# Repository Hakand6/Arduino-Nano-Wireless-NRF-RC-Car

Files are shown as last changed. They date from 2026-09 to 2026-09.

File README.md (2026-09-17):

# Arduino-Nano-Wireless-NRF-RC-Car
# DIY Wireless RC Car & Custom Transmitter

Bu proje, tamamen sıfırdan tasarlanmış ve üretilmiş, kablosuz (RF) iletişimle kontrol edilen özel bir uzaktan kumandalı araba ve kumanda sistemidir. Hem donanımsal hem de yazılımsal olarak tüm süreçler (3D tasarım, devre tasarımı ve Arduino kodlaması) bu repoda yer almaktadır.

 Kullanılan Bileşenler

### Araç (Alıcı Tarafı):
* **Mikrokontrolcü:** Arduino Nano
* **Kablosuz Haberleşme:** NRF24L01 Transceiver Modülü
* **Motor Kontrolü:** Çift kanallı röle modülü & Güçlü DC Motor
* **Güç Yönetimi:** 12V Batarya ve ekranlı/voltaj göstergeli voltaj regülatörü
* **Aydınlatma:** Alt taban RGB LED aydınlatma
* **Şasi:** Özel 3D tasarım ve baskı parça bileşenleri

### Kumanda (Verici Tarafı):
* **Mikrokontrolcü:** Arduino Nano
* **Kablosuz Haberleşme:** NRF24L01 Transceiver Modülü
* **Giriş Elemanları:** Joystick ve potansiyometreler (Adaptif hız kontrolü için)

##  Özellikler
* **Özel Tasarım Kumanda:** Ergonomik, kendi üretimimiz olan 3D baskı kumanda kasası.
* **Adaptif Hız Kontrolü:** Kumanda üzerindeki girdilere duyarlı olarak anlık hız artırıp azaltabilme.
* **Canlı Voltaj Takibi:** Ekranlı regülatör sayesinde anlık batarya voltajı izleme (düşük voltaj/şarj bitti uyarısı).
* **Kablosuz Kontrol:** NRF24L01 modülleri ile kesintisiz ve kararlı sinyalleşme.
* **Görsel Detaylar:** Aracın alt kısmına entegre edilmiş RGB LED'ler.

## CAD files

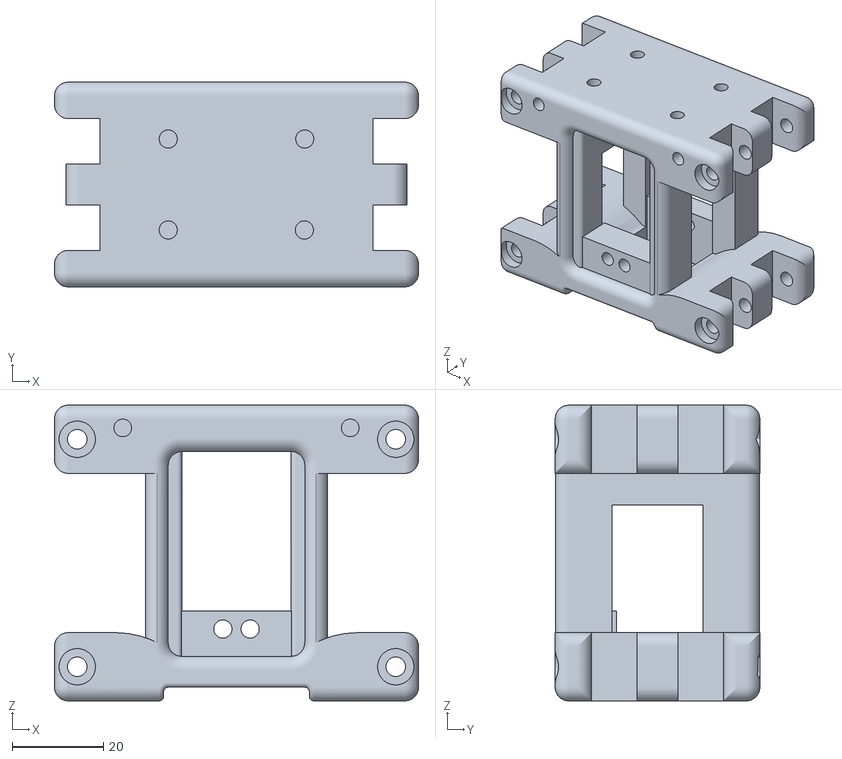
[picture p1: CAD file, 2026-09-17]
3d Printed Files/Main Suspension Hub Connector Front.STL
80.0 x 45.0 x 65.0

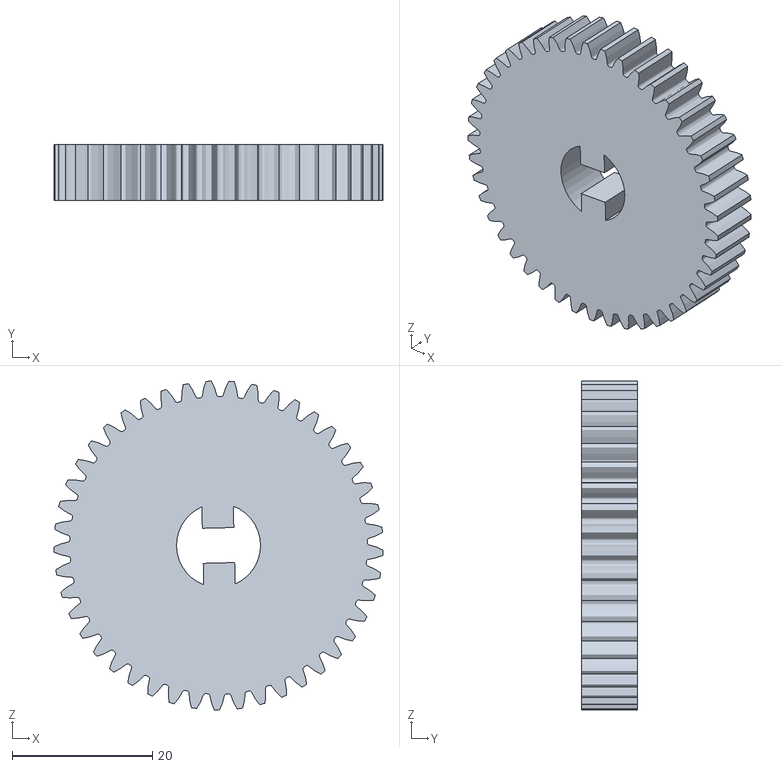
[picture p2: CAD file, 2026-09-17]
3d Printed Files/Gearbox Assembly - 45 Teeth Gear-1.STL
47.0 x 8.00 x 47.0

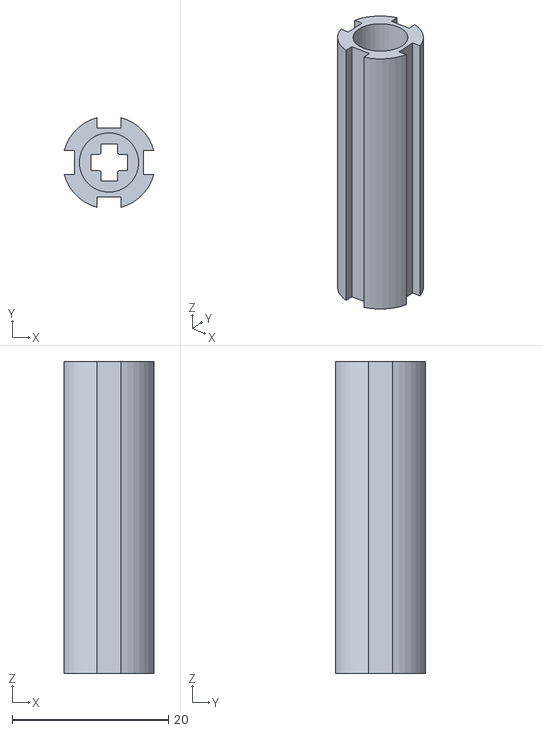
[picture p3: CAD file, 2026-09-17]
3d Printed Files/Main Rear Axle.STL
11.5 x 11.5 x 40.0

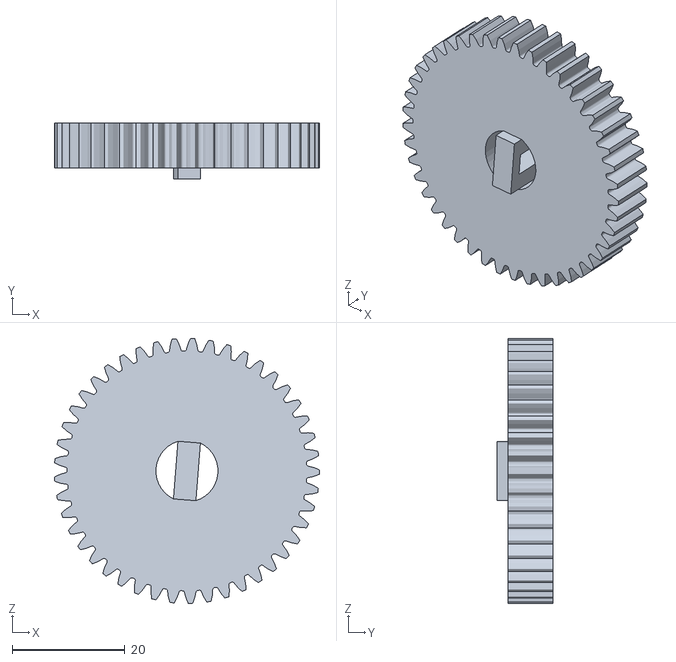
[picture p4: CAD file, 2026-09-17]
3d Printed Files/Gearbox Assembly - 45 15 Gear (2).STL
47.0 x 10.0 x 47.0

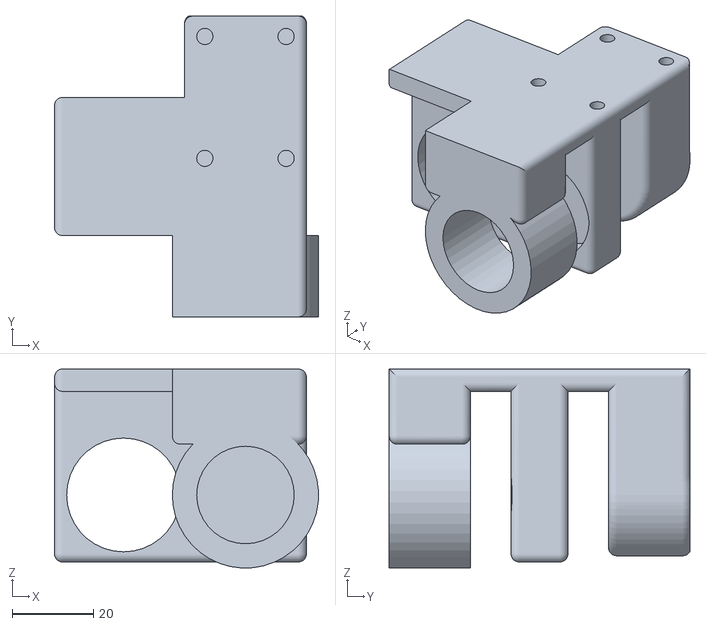
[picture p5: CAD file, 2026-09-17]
3d Printed Files/Gearbox Assembly - Motor Mount-1.STL
65.0 x 74.0 x 49.0

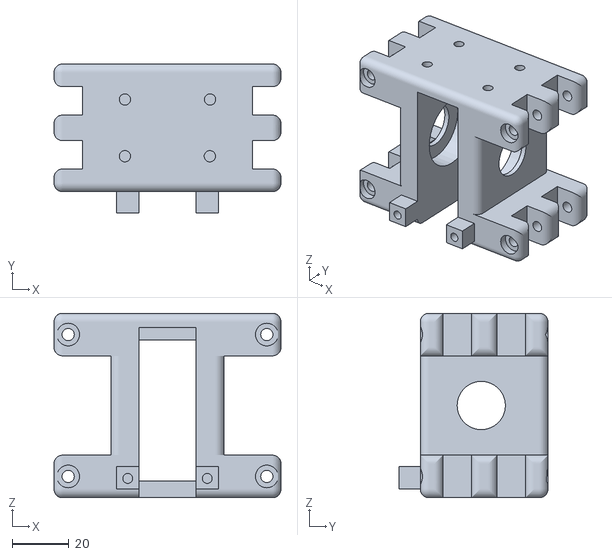
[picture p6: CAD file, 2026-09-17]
3d Printed Files/Main Suspension Hub Connector Rear.STL
80.0 x 52.5 x 65.0

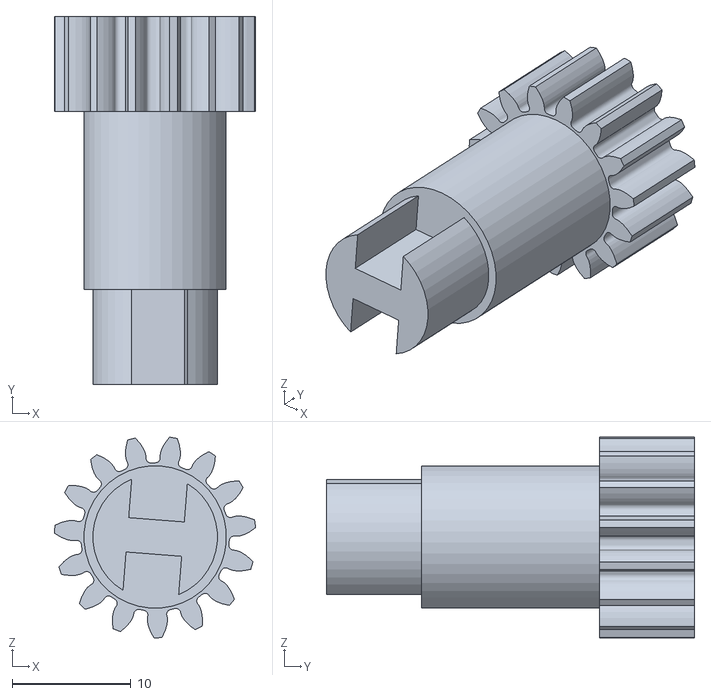
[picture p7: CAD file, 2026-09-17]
3d Printed Files/Gearbox Assembly - 45 15 Gear (1).STL
17.0 x 31.0 x 16.9

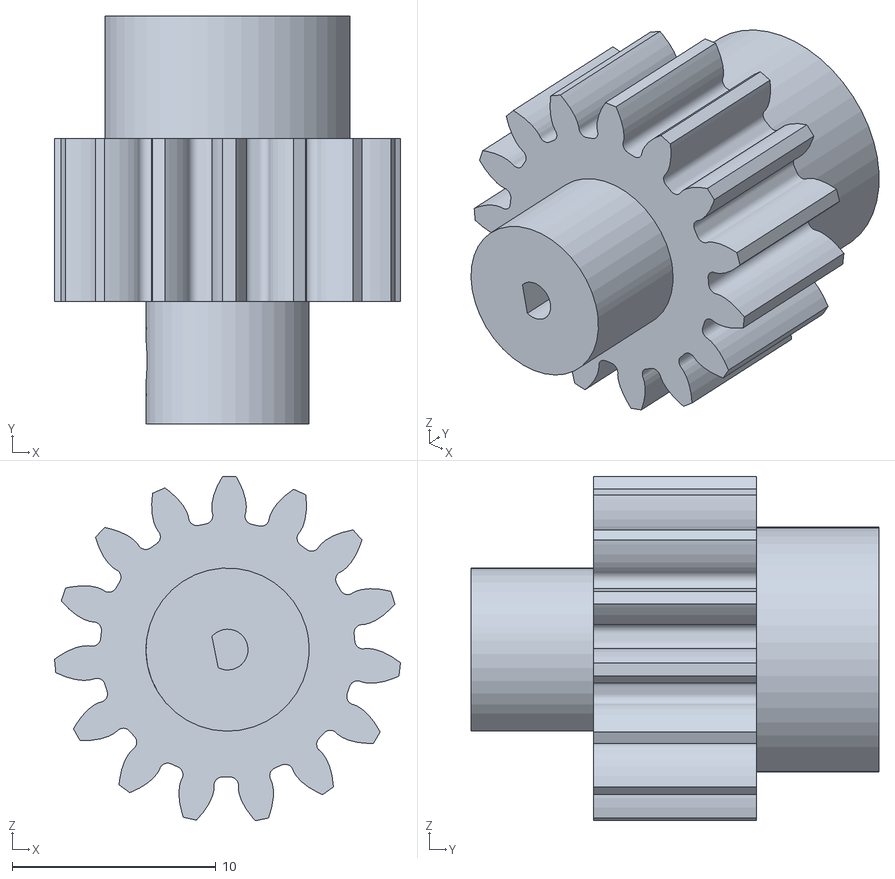
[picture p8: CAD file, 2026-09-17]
3d Printed Files/Gearbox Assembly - Motor Gear-1.STL
17.0 x 20.0 x 16.9

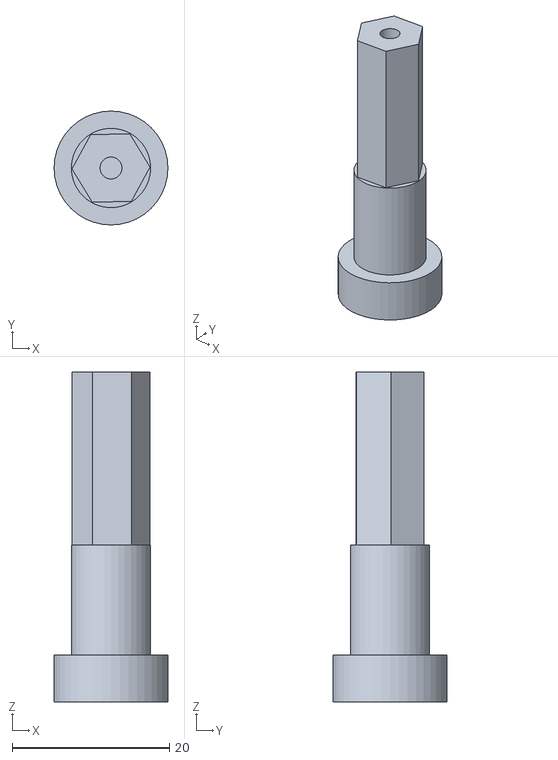
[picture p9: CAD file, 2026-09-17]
3d Printed Files/Front Wheel Connector.STL
14.5 x 14.5 x 42.0

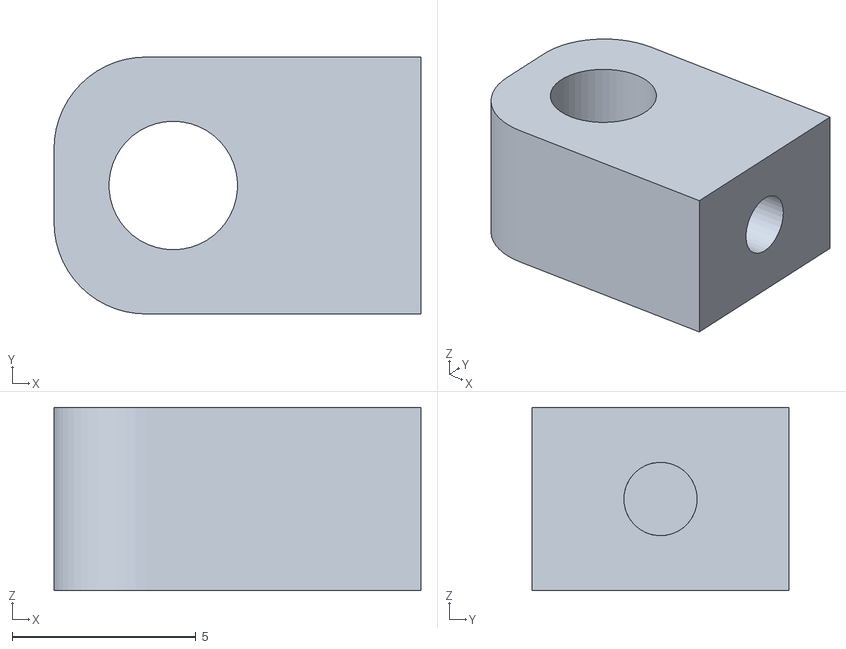
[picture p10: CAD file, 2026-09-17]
amortısor/obj_4_实体9.stl
10.0 x 7.00 x 5.00

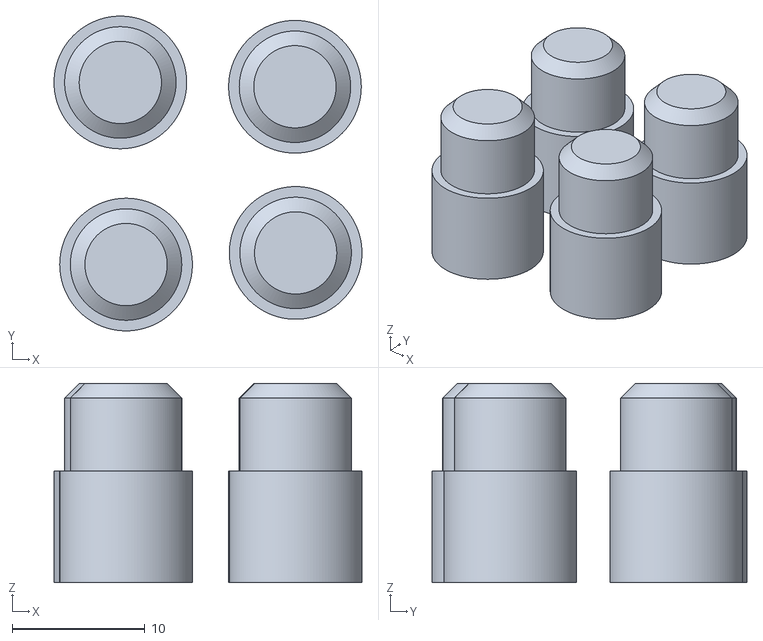
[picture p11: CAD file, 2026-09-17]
rc kumanda/obj_1_Buttons.stl
23.2 x 23.7 x 15.0

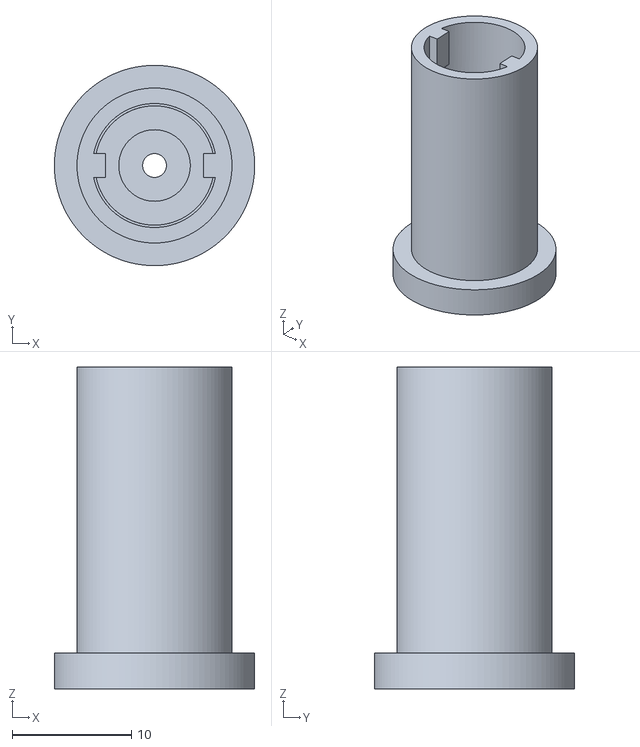
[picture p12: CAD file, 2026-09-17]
amortısor/obj_2_实体2.stl
16.8 x 16.8 x 27.0

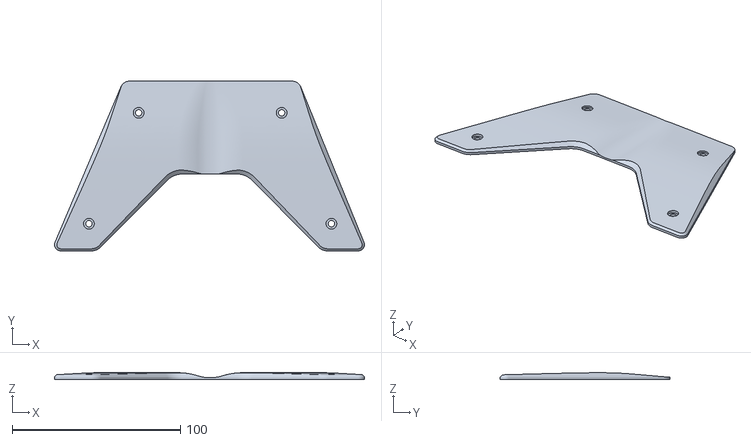
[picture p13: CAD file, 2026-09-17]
rc kumanda/obj_2_COMPOUND_6.stl
184.0 x 100.8 x 3.92

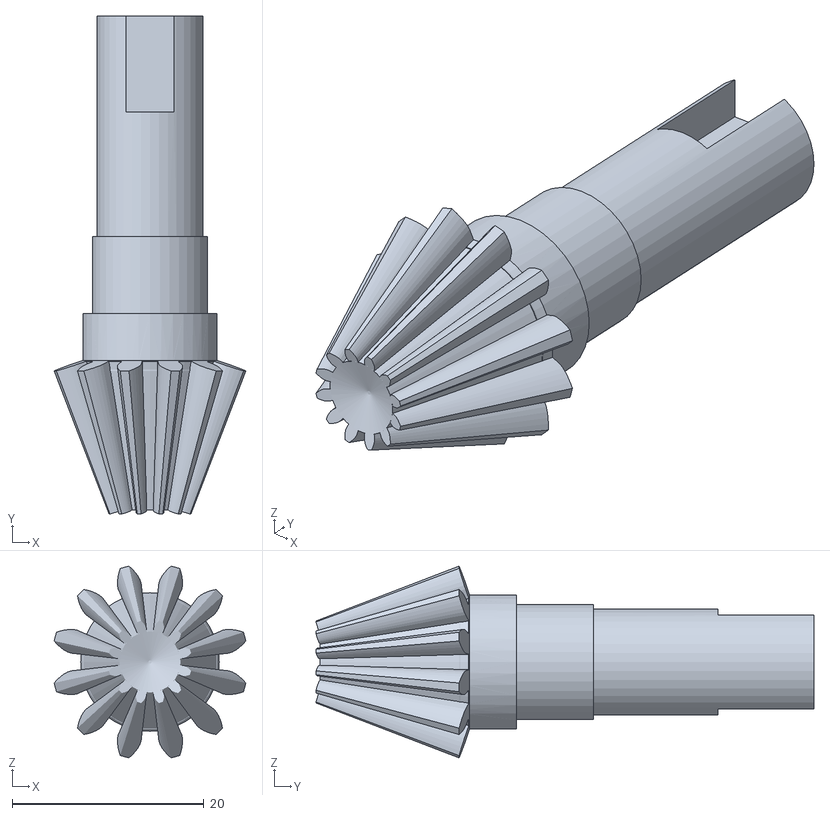
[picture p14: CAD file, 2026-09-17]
3d Printed Files/Small Bevel Gear.STL
20.0 x 51.9 x 20.0

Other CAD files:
amortısor/obj_3_实体1.stl
rc kumanda/rc kumada kapak.stl
3d Printed Files/Steering Arm Bottom.STL
amortısor/obj_1_实体1.stl
3d Printed Files/Bumper.STL
3d Printed Files/Frame.STL
3d Printed Files/Front Wheel Hub.STL
3d Printed Files/Large Bevel Gear.STL
3d Printed Files/Rear Wheel Connector.STL
3d Printed Files/Rear Wheel Hub Left.STL
3d Printed Files/Rear Wheel Hub Right.STL
3d Printed Files/ServoMount.STL
3d Printed Files/Shock Absorber Extension - Rear Suspension Hub.STL
3d Printed Files/Spacer.STL
3d Printed Files/Steering Arm Top.STL
3d Printed Files/Steering Connector.STL
3d Printed Files/Suspension Arm DRIVING WHEEL.STL
3d Printed Files/Wheel Spacer.STL
rc kumanda/rc kumada kasa.stl

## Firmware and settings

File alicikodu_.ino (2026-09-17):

#include <SPI.h>
#include <nRF24L01.h>
#include <RF24.h>
#include <Servo.h>

RF24 radio(9, 10); // CE: D9, CSN: D10
const byte address[6] = "RC775";

// Pin Tanımlamaları
const int MOSFET_ALT_LED   = 2;  // IRLZ44N Alt Işık PWM (D2)
const int MOSFET_MOTOR_PWM = 3;  // HW-517 Motor Hız PWM (D3)
const int ROLE_IN1         = 4;  // Çift Kanal Röle 1 (D4)
const int ROLE_IN2         = 5;  // Çift Kanal Röle 2 (D5)
const int SERVO_PIN        = 6;  // Direksiyon Servosu (D6)
const int LED_SYSTEM       = 7;  // Alıcı Sistem/Bağlantı LED'i (D7)

Servo direksiyon;

// Vericiden Gelen Paket
struct Data_Package {
  int gazVal = 512;
  int yonVal = 512;
  byte maxHiz = 255;
  byte isikHiz = 0;
};

Data_Package data;
unsigned long sonSinyalZamani = 0;
static int sonYon = 0; // 0: Nötr, 1: İleri, 2: Geri

void setup() {
  pinMode(MOSFET_MOTOR_PWM, OUTPUT);
  pinMode(MOSFET_ALT_LED, OUTPUT);
  pinMode(LED_SYSTEM, OUTPUT);
  
  pinMode(ROLE_IN1, OUTPUT);
  pinMode(ROLE_IN2, OUTPUT);
  
  // Başlangıç durumları
  analogWrite(MOSFET_MOTOR_PWM, 0);
  digitalWrite(ROLE_IN1, HIGH);
  digitalWrite(ROLE_IN2, HIGH);
  digitalWrite(LED_SYSTEM, LOW);

  direksiyon.attach(SERVO_PIN);
  direksiyon.write(90); // Başlangıçta tekerler düz

  radio.begin();
  radio.openReadingPipe(0, address);
  radio.setPALevel(RF24_PA_MAX);
  radio.startListening();
}

void loop() {
  if (radio.available()) {
    radio.read(&data, sizeof(Data_Package));
    sonSinyalZamani = millis();
    digitalWrite(LED_SYSTEM, HIGH); // Sinyal varken D7 LED'i SABİT YANAR
  }

  // FAIL-SAFE: 1 saniyeden fazla sinyal koparsa güvenliğe geç
  if (millis() - sonSinyalZamani > 1000) {
    analogWrite(MOSFET_MOTOR_PWM, 0);
    analogWrite(MOSFET_ALT_LED, 0);
    direksiyon.write(90);
    
    // Sinyal yokken D7 Ledi yanıp söner (Blink uyarısı)
    digitalWrite(LED_SYSTEM, (millis() / 300) % 2); 
    return;
  }

  // 1. ALT LED PARLAKLIK KONTROLÜ (IRLZ44N)
  analogWrite(MOSFET_ALT_LED, data.isikHiz);

  // 2. ORANSAL DİREKSİYON (SERVO) KONTROLÜ
  int servoAcisi = map(data.yonVal, 0, 1023, 60, 120);
  servoAcisi = constrain(servoAcisi, 60, 120);
  direksiyon.write(servoAcisi);

  // 3. KADEMELİ GAZ VE RÖLE KONTROLÜ
  int gaz = data.gazVal;
  
  // İLERİ SÜRÜŞ
  if (gaz > 540) {
    if (sonYon == 2) { 
      analogWrite(MOSFET_MOTOR_PWM, 0); // Ani yön değişim koruması
      delay(150);
    }
    digitalWrite(ROLE_IN1, LOW);
    digitalWrite(ROLE_IN2, HIGH);

    int hedefHiz = map(gaz, 541, 1023, 0, data.maxHiz);
    analogWrite(MOSFET_MOTOR_PWM, hedefHiz);
    sonYon = 1;
  } 
  // GERİ SÜRÜŞ
  else if (gaz < 480) {
    if (sonYon == 1) { 
      analogWrite(MOSFET_MOTOR_PWM, 0); // Ani yön değişim koruması
      delay(150);
    }
    digitalWrite(ROLE_IN1, HIGH);
    digitalWrite(ROLE_IN2, LOW);

    int hedefHiz = map(gaz, 479, 0, 0, data.maxHiz);
    analogWrite(MOSFET_MOTOR_PWM, hedefHiz);
    sonYon = 2;
  } 
  // DURMA / NÖTR BÖLGE
  else {
    analogWrite(MOSFET_MOTOR_PWM, 0);
    digitalWrite(ROLE_IN1, HIGH);
    digitalWrite(ROLE_IN2, HIGH);
    sonYon = 0;
  }
}

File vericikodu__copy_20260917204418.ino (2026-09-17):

#include <SPI.h>
#include <nRF24L01.h>
#include <RF24.h>

RF24 radio(9, 10); // CE: D9, CSN: D10
const byte address[6] = "RC775";

// Analog Pin Tanımlamaları
const int POT_ISIK   = A0; // Pot 2 (Alt LED Parlaklığı)
const int POT_HIZ    = A1; // Pot 1 (Maksimum Hız Limiti)
const int JOY_YON    = A2; // Joystick 2 Direksiyon (Ters Invert)
const int JOY_GAZ    = A3; // Joystick 1 Gaz

const int LED_POWER  = 2;  // Güç Ledi (D2)
const int LED_CONN   = 3;  // Bağlantı Ledi (D3)

// Gönderilecek Veri Paketi
struct Data_Package {
  int gazVal = 512;    // 0 - 1023 (Ham Analog Değer)
  int yonVal = 512;    // 0 - 1023 (Ham Analog Değer)
  byte maxHiz = 255;   // 0 - 255 (Pot 1)
  byte isikHiz = 0;    // 0 - 255 (Pot 2)
};

Data_Package data;

void setup() {
  Serial.begin(9600);
  while (!Serial) { ; }

  pinMode(LED_POWER, OUTPUT);
  pinMode(LED_CONN, OUTPUT);
  digitalWrite(LED_POWER, HIGH); // Kumanda çalıştı, Güç LED'i yansın

  Serial.println("\n================================================");
  Serial.println("   GELISMIS RC KUMANDA SİSTEMİ BAŞLATILDI     ");
  Serial.println("================================================\n");

  radio.begin();
  radio.openWritingPipe(address);
  radio.setPALevel(RF24_PA_MAX); // Yüksek menzil gücü
  radio.stopListening();
}

void loop() {
  // 1. ANALOG SENSÖR OKUMALARI
  data.gazVal  = analogRead(JOY_GAZ);
  
  // Joystick ters monte edildiği için yazılımsal olarak yönü düzeltiyoruz
  data.yonVal  = 1023 - analogRead(JOY_YON); 
  
  data.maxHiz  = map(analogRead(POT_HIZ), 0, 1023, 0, 255);
  data.isikHiz = map(analogRead(POT_ISIK), 0, 1023, 0, 255);

  // 2. VERİ PAKETİNİ ALICIYA GÖNDERME
  bool baglantiVar = radio.write(&data, sizeof(Data_Package));

  // 3. BAĞLANTI LEDİ KONTROLÜ
  if (baglantiVar) {
    digitalWrite(LED_CONN, HIGH); // Alıcıdan onay geldikçe D3 Ledi YANAR
  } else {
    digitalWrite(LED_CONN, LOW);  // Alıcı kapalıysa/sinyal yoksa D3 SÖNER
  }

  // 4. CANLI TELEMETRİ VE NRF DURUM ÇIKTISI (SERİ PORT)
  Serial.print("POT1(Hız Limit): "); Serial.print(data.maxHiz);
  Serial.print(" | POT2(Işık): "); Serial.print(data.isikHiz);

  Serial.print(" | GAZ(A3): ");
  if(data.gazVal > 540)      Serial.print("[İLERİ KADEMELİ]");
  else if(data.gazVal < 480) Serial.print("[GERİ KADEMELİ]");
  else                        Serial.print("[DUR]");

  Serial.print(" | YÖN(A2): ");
  if(data.yonVal > 540)      Serial.print("[SAĞ KADEMELİ]");
  else if(data.yonVal < 480) Serial.print("[SOL KADEMELİ]");
  else                        Serial.print("[DÜZ]");

  if (baglantiVar) {
    Serial.println(" | NRF: [ÇALIŞIYOR & ALICI ONAYLADI]");
  } else {
    Serial.println(" | NRF: [ÇİP AKTİF / ALICI YANIT VERMİYOR]");
  }

  delay(20); // 50 Hz yenileme hızı (Hızlı ve hassas tepki süresi)
}
